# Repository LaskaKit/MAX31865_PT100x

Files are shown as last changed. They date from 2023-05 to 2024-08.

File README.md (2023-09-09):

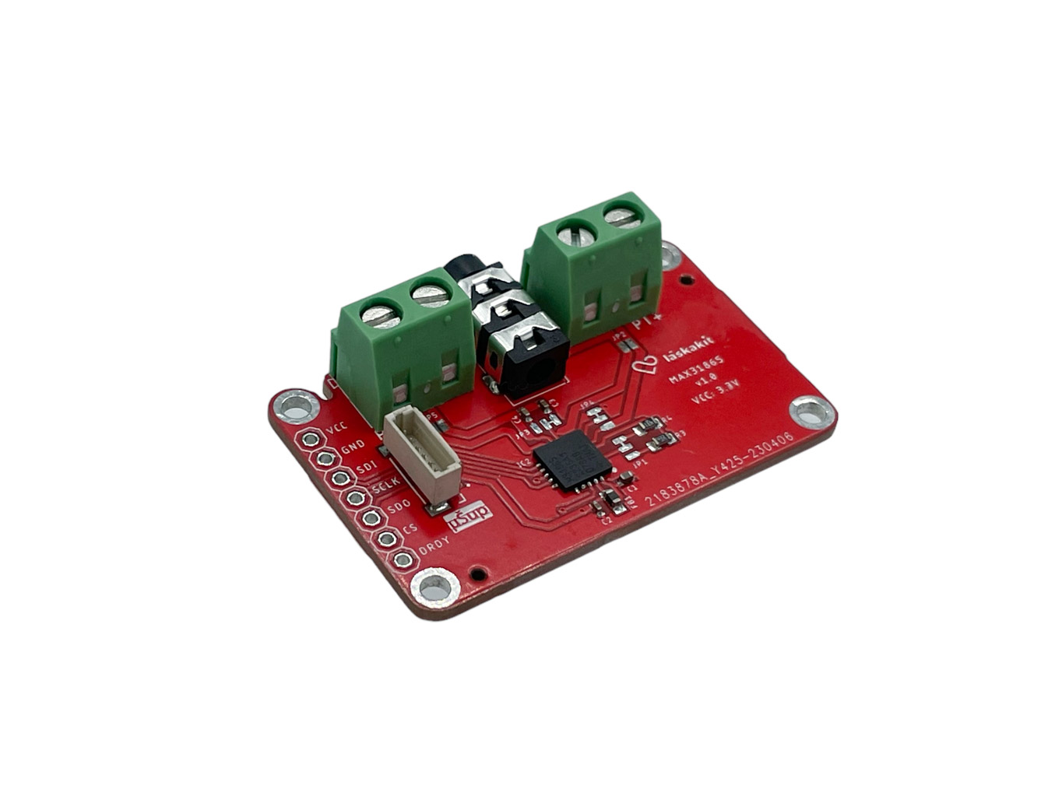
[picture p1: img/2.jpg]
TOP strana modulu


# LaskaKit MAX31865 converter for PT100 and PT1000

Converter module for PT100 and PT1000 platinum temperature sensors with SPI interface. Thanks to the MAX31865 chip, highly accurate measurement results are achieved for both four-wire and three-wire PTC sensors. The converter also supports two-wire sensors. However, for these, the accuracy cannot be expected to be as high as for multi-wire sensors. Communication with the microcontroller is via the SPI interface and the module has an integrated logic level translator so the module can be operated with 5V power and 3.3V logic, or vice versa.

The module is supplied in a configuration for the use of PTC sensors type PT100. If the module is to be used with a PT1000 type sensor, jumpers JP1 and JP3 must be cut and connected to the other side.

Setting the number of wires:</br>
4-wire sensors: JP2 and JP5 disconnected, JP4 connected at the top (default)</br>
3 wire sensors: JP2 disconnected, JP5 connected, JP4 connected down</br>
2 wire sensors: JP2 and JP5 connected, JP4 connected on top</br>

## The module is available on https://www.laskakit.cz/laskakit-max31865-prevodnik-pro-termoclanek-pt100-1000/

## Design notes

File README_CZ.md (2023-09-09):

TOP strana modulu

# LaskaKit MAX31865 převodník pro termočlánek PT100x

Modul převodníku pro teplotní platinová čidla PT100 a PT1000 s rozhraním SPI. Díky použitému čipu MAX31865 je dosahováno vysoce přesných výsledků měření jak pro PTC čidla se čtyřmi vodiči, tak se třemi vodiči. Převodník podporuje i čidla dvouvodičová. U těch však nelze očekávat tak velkou přesnost, jako více vodičových čidel. Komunikace s mikrokontrolerem je pomocí rozhraní SPI a modul má integrován překladač logických úrovní a tak lze modul provozovat s 5V napájením a 3.3V logikou, popř. obráceně.

Modul je dodáván v konfiguraci pro použití PTC čidel typu PT100. Pokud je potřeba použít modul s čidlem typu PT1000, je nutné rozříznou a zapojit s jiné strany jumpry JP1 a JP3.

Nastavění počtu vodičů:</br>
4 vodičové senzory: JP2 a JP5 rozpojený, JP4 propojený nahoře (default)</br>
3 vodičové senzory: JP2 rozpojený, JP5 propojený, JP4 propojený dolé</br>
2 vodičové senzory: JP2 a JP5 propojený, JP4 propojený nahoře</br>

## Modul je dostupný na https://www.laskakit.cz/laskakit-max31865-prevodnik-pro-termoclanek-pt100-1000/

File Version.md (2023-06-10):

### Version 1.1
- uSup SPI connector changed | Změná uSup konektoru
#### Version 1.0
- Initial | Počáteční

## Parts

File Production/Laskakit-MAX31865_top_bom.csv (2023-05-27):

Comment | Designator | Footprint | LCSC Part #
4.3k | R3 | R0603 | C861441
10nF | C4 | C0402
22uF | C1 | C0402
100nF | C2 C3 | C0402
430 | R4 | R0603 | C705855
BLM18AG601SN1D | FB1 | R0603 | C19330
JST-SH-6_VERT | J2 | 1X06_1MM_RA_VERT | C145963
MAX31865ATP+T | IC2 | QFN65P500X500X80-21N | C118474
SJ35 | X1 | PJ-313 | C388632

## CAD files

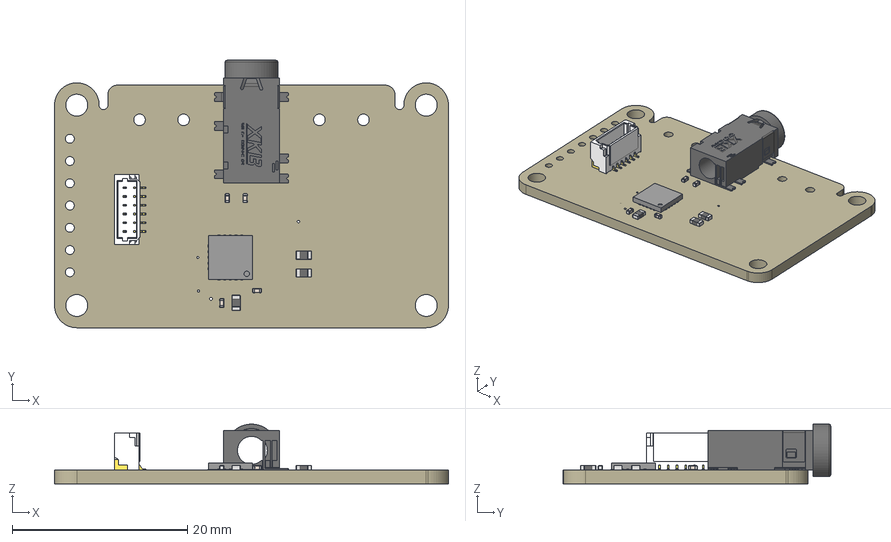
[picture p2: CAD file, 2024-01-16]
3D/Laskakit-MAX31865 v11.step
45.0 x 30.5 x 6.82 mm
Board
R0603
LASKKIT_10MM_SILKSCREEN
USUP_4MM_SILKSCREEN
1X06_1MM_RA_VERT
ThermalPin
PinsArrayLR
PinsArrayTB
PJ-342B-TX-SMT
SPI_4MM_SILKSCREEN
Pin1 x 4
Pin2 x 4
CeramicBody x 4
2,5-PAD x 4
R0603 (1) x 2

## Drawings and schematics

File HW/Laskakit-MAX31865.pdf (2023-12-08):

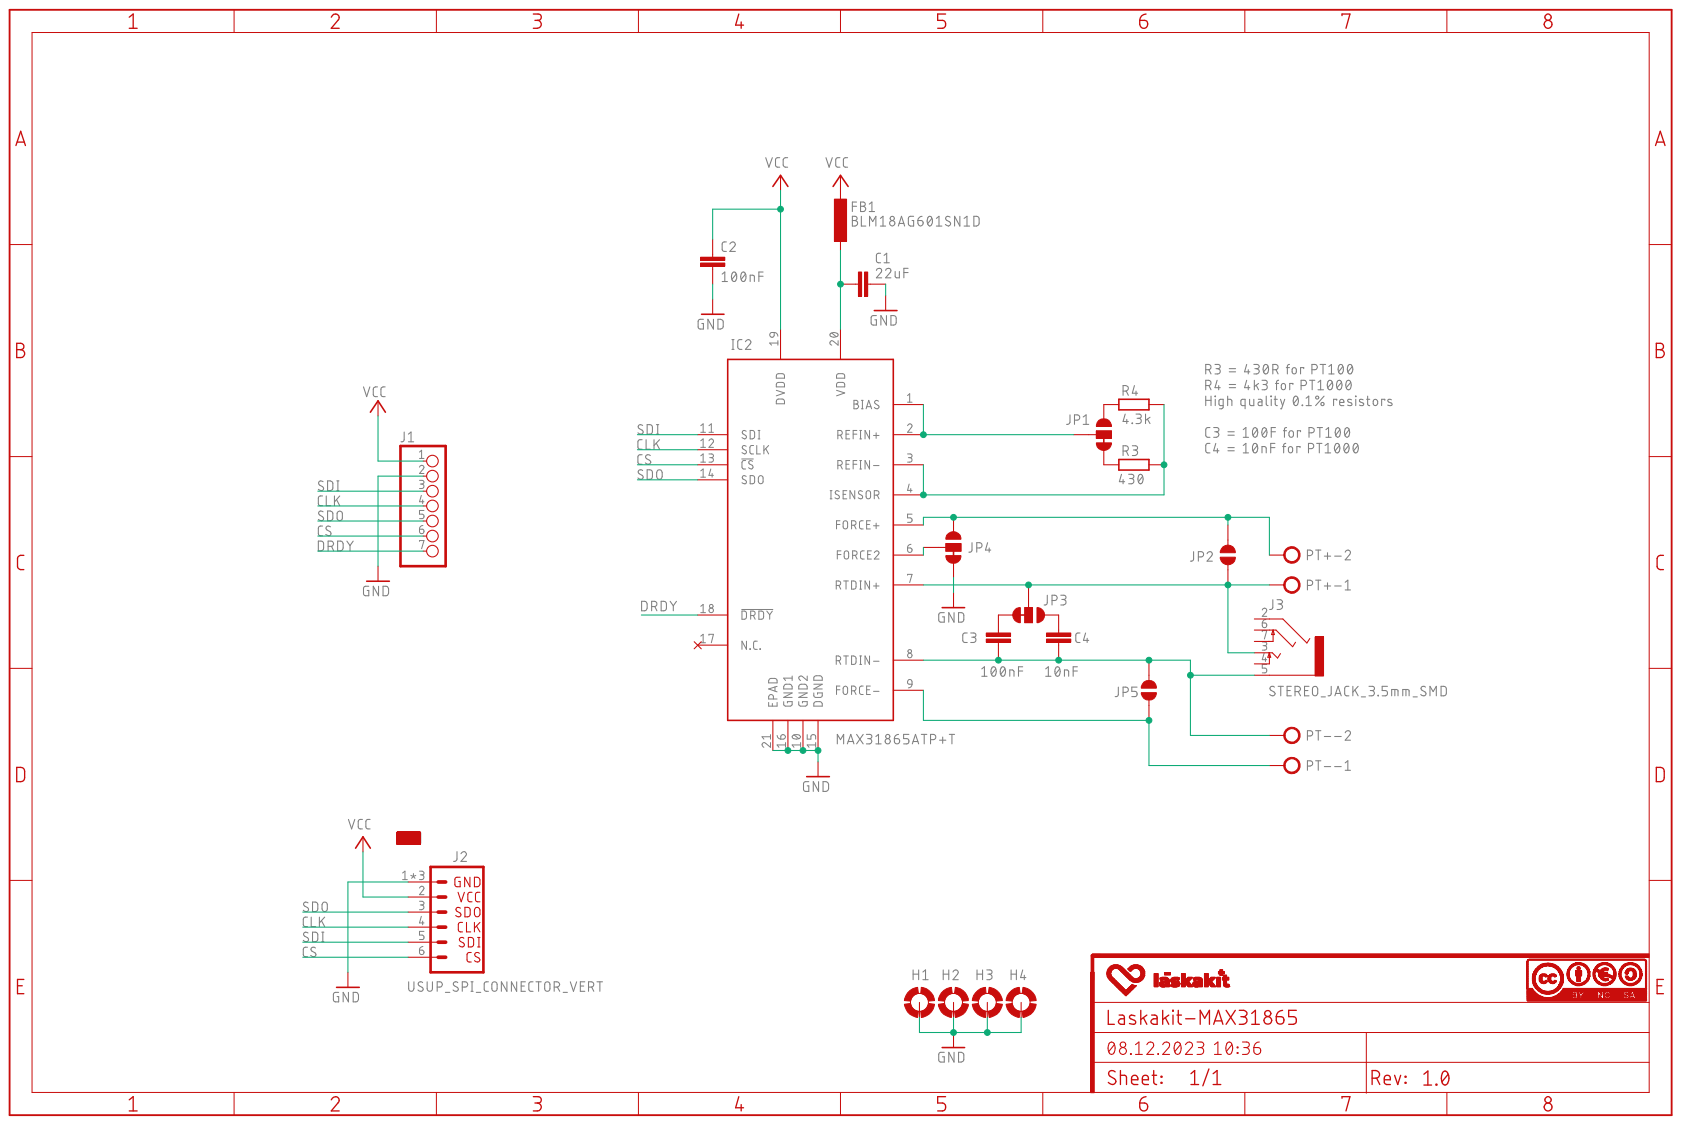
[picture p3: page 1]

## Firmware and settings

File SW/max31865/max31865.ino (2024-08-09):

// LaskaKIT MAX31865

#include <Adafruit_MAX31865.h>

//#define LaskaKitESP32DEV
//#define LaskaKitESP32S3
#define LaskaKitESPink426

#ifdef LaskaKitESP32DEV
  #define MOSI  13
  #define MISO  12
  #define SCK   14
  #define CS    15
  #define POWER 2
#elif defined LaskaKitESP32S3
  #define MOSI  11
  #define MISO  13
  #define SCK   12
  #define CS    10
  #define POWER 47
#elif defined LaskaKitESPink426
  #define MOSI  37
  #define MISO  21
  #define SCK   14
  #define CS    46
  #define POWER 47
#endif

Adafruit_MAX31865 thermo = Adafruit_MAX31865(CS, MOSI, MISO, SCK);

#define PT1000  // select sensor type: PT100 or PT1000

#if defined(PT1000)
  #define RREF      4300.0
  #define RNOMINAL  1000.0
#elif defined(PT100)
  #define RREF      430.0
  #define RNOMINAL  100.0
#endif

void setup() {
  Serial.begin(115200);
  pinMode(POWER, OUTPUT); 
  digitalWrite(POWER, HIGH); // enable power supply for ePaper and uSup
  delay(500);

  Serial.println("MAX31865 PT100/PT1000 Sensor Test!");

  thermo.begin(MAX31865_2WIRE);  // set to 2WIRE, 3WIRE or 4WIRE as necessary
}


void loop() {
  uint16_t rtd = thermo.readRTD();

  Serial.print("RTD value: "); Serial.println(rtd);
  float ratio = rtd;
  ratio /= 32768;
  Serial.print("Ratio = "); Serial.println(ratio,8);
  Serial.print("Resistance = "); Serial.println(RREF*ratio,8);
  Serial.print("Temperature = "); Serial.println(thermo.temperature(RNOMINAL, RREF));

  // Check and print any faults
  uint8_t fault = thermo.readFault();
  if (fault) {
    Serial.println("Mas spravne zapojeny senzor? Mas spravne zvoleny typ senzoru - PT100/PT100? Nebo spatne nastavene propojky?");
    Serial.print("Fault 0x"); Serial.println(fault, HEX);
    if (fault & MAX31865_FAULT_HIGHTHRESH) {
      Serial.println("RTD High Threshold"); 
    }
    if (fault & MAX31865_FAULT_LOWTHRESH) {
      Serial.println("RTD Low Threshold"); 
    }
    if (fault & MAX31865_FAULT_REFINLOW) {
      Serial.println("REFIN- > 0.85 x Bias"); 
    }
    if (fault & MAX31865_FAULT_REFINHIGH) {
      Serial.println("REFIN- < 0.85 x Bias - FORCE- open"); 
    }
    if (fault & MAX31865_FAULT_RTDINLOW) {
      Serial.println("RTDIN- < 0.85 x Bias - FORCE- open - "); 
    }
    if (fault & MAX31865_FAULT_OVUV) {
      Serial.println("Under/Over voltage"); 
    }
    thermo.clearFault();
  }
  Serial.println();
  delay(1000);
}

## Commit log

2023-05-27 small design update
    [Laskakit-MAX31865_top_bom.csv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]
2024-01-16 Create Laskakit-MAX31865 v11.step
    [Laskakit-MAX31865 v11.step]
2024-01-19 new data
    [Laskakit-MAX31865_top_bom 2.csv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]
